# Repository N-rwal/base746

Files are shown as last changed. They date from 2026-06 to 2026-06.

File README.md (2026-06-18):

# base746 Radar Project




---

<details>
<summary>Com fixes</summary>

1. usb fix:  `sudo chmod 666 /dev/ttyACM0`
2. missing arch module: `sudo pacman -S openocd libusb`

</details>

**Description du capteur ou de l'actionneur**

 

Le LD2450 est un module de capteur de suivi de cible en mouvement de la série de radars à ondes millimétriques Hilink 24G.
Il comprend un capteur radar 24 GHz extrêmement simplifié et un micrologiciel doté d'un algorithme intelligent. Cette solution est principalement utilisée dans des environnements intérieurs tels que les maisons, les bureaux et les hôtels pour permettre le suivi de la localisation de personnes en mouvement. Le capteur est composé d'une puce radar à ondes millimétriques AloT, d'une antenne microruban haute performance à un émetteur et deux récepteurs, d'un microcontrôleur économique et de circuits auxiliaires périphériques. Le micrologiciel utilise des formes d'onde FMCW et la technologie de traitement du signal avancée propriétaire de la puce radar.
Il prend en charge la sortie série des données de détection, est prêt à l'emploi et peut être facilement intégré à différents environnements intelligents et produits finaux.

---

**Description de la liaison et principe de fonctionnement hardware
type d'alimentation, type de communication**




Le module LD2450 communique directement via le port série conformément au protocole prescrit pour la sortie des données de résultats de détection:
https://drive.google.com/drive/folders/1kTt0Z3hjKKrIF3OCIDGdwQ4KotDJ8SGA

Les données de sortie série contiennent jusqu'à trois cibles, leur position et leur vitesse, ainsi que d'autres informations. L'utilisateur peut les utiliser de manière flexible
selon les scénarios d'application spécifiques. La tension d'alimentation du module est de 5 V et la capacité de l'alimentation
d'entrée doit être supérieure à 200 mA. Le niveau de sortie E/S du module est de 3,3 V. Le débit en bauds par défaut du port série est de
256 000, avec 1 bit d'arrêt et sans bit de parité. 5.2.

---

**Schéma et typon de raccordement à la carte DISCO**

La carte d'origine est conçue pour accepter les modules de type Arduino Uno.


Nous avons donc utilisé le modèle Arduino. J'ai ajouté au circuit un connecteur XT30 pour l'alimentation par batterie et un port supplémentaire pour les E/S à usage général (GPIO),
au cas où nous en aurions besoin.



Le circuit imprimé obtenu est simple face, plutôt compact et s'adapte comme prévu.


---

**Description de la liaison et principe de fonctionnement software bibliothèques utilisées**

Le fichier LD2450.cpp implémente le pilote radar LD2450 : il lit les octets depuis une interface série matérielle (HardwareSerial), analyse les trames radar pour extraire jusqu’à trois cibles (coordonnées x et y, vitesse, résolution spatiale) et les stocke dans un tampon interne accessible via la fonction getTargets(). Il décode également les valeurs signées 16 bits, reconnaît les trames d’accusé de réception (ACK) et fournit des fonctions d’assistance (setSingleTargetMode, setMultiTargetMode, restart, factoryReset) qui construisent et envoient des trames de commande et attendent (avec un délai d’attente de 200 ms) la réception des accusés de réception correspondants. L’analyse consiste en une simple lecture du tampon qui copie les cibles analysées de manière atomique, et la fonction processByte() ajoute les octets entrants et déclenche l’analyse lorsque suffisamment de données sont accumulées.

---

**Description du fonctionnement de l'application réalisée**

- **Fonction :** Lit les données du radar LD2450 via UART, analyse jusqu'à trois cibles et les affiche sous forme de texte et d'une visualisation graphique simple.
- **Matériel / E/S :** Utilise le port `Serial6` (broches `TX_PIN`/`RX_PIN` → `PC6`/`PC7`) pour communiquer avec le module radar LD2450.
- **Interface utilisateur :** Interface à trois onglets basée sur LVGL : l'onglet 1 affiche les étiquettes `target1_label`, `target2_label` et `target3_label` (texte), l'onglet 2 est `radar_viz_container` avec `target_dots[]` (graphique), l'onglet 3 est un espace réservé.
- **Flux d'exécution :** `mySetup()` construit l'interface utilisateur et configure l'UART, puis lance la tâche FreeRTOS `myTask()`. La fonction `myTask()` lit les octets, appelle `radar.processByte()`, obtient les cibles via `radar.getTargets()`, puis met à jour l'interface utilisateur LVGL (étiquettes + `update_target_dots()`).
- **Logique de visualisation :** `update_target_dots()` convertit les coordonnées en millimètres en positions en pixels, les limite à la zone visible et affiche/masque les points ; des coordonnées nulles signifient « aucune cible ».
- **Remarque concernant la concurrence :** Les mises à jour LVGL sont protégées par `lv_lock()` / `lv_unlock()` car LVGL n'est pas thread-safe.









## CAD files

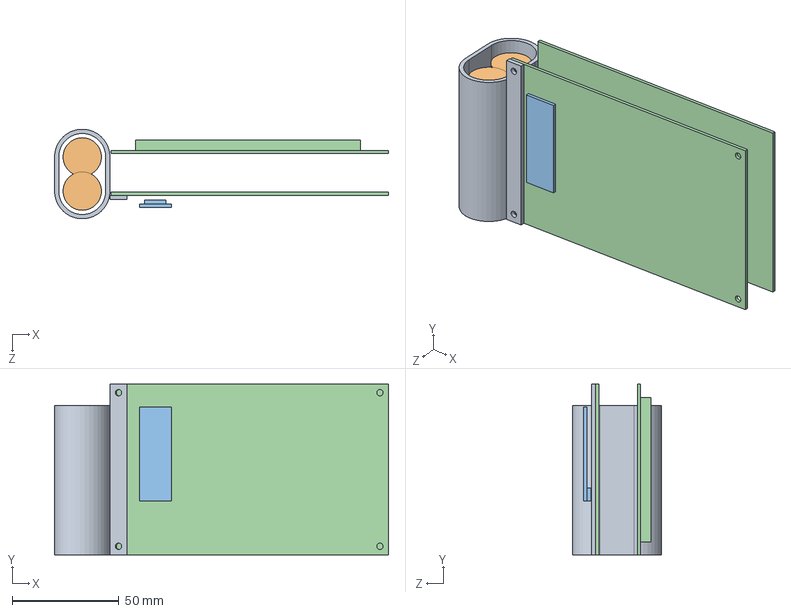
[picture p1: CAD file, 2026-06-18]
project data/radar_handheld/Assemblage1.SLDASM
156.5 x 80.0 x 41.9 mm
stm
radar
cell x 2
holder

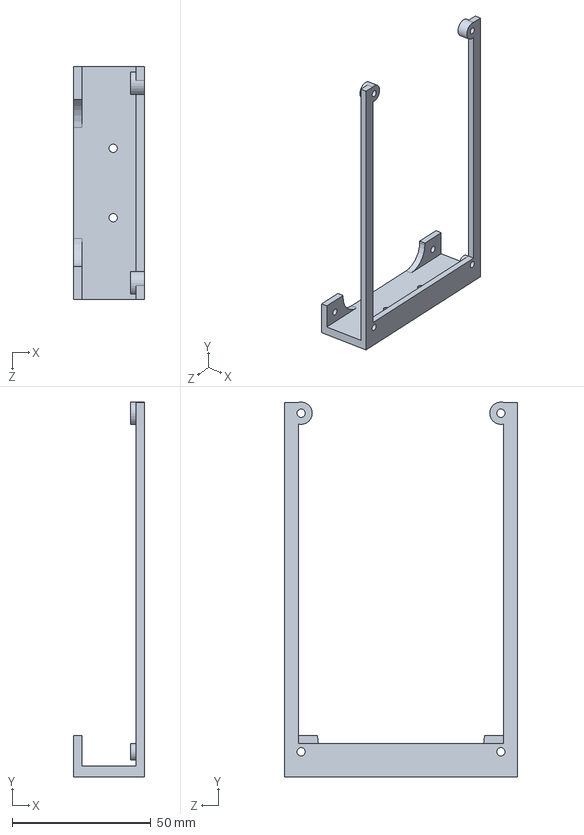
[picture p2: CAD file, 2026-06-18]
project data/radar_handheld/support.SLDPRT
25.5 x 135.1 x 84.0 mm

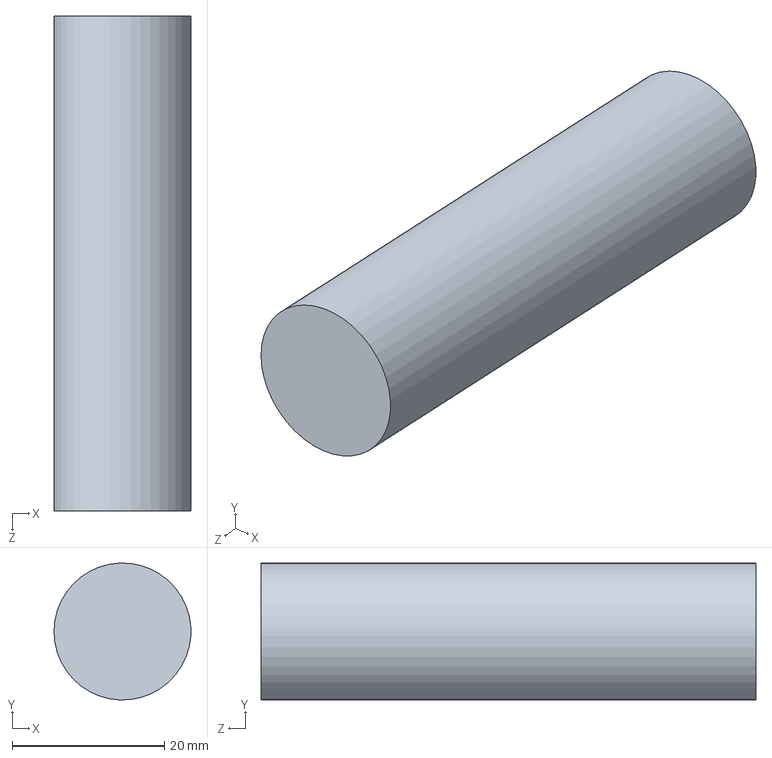
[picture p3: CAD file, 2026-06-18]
project data/radar_handheld/cell.SLDPRT
18.0 x 18.0 x 65.0 mm

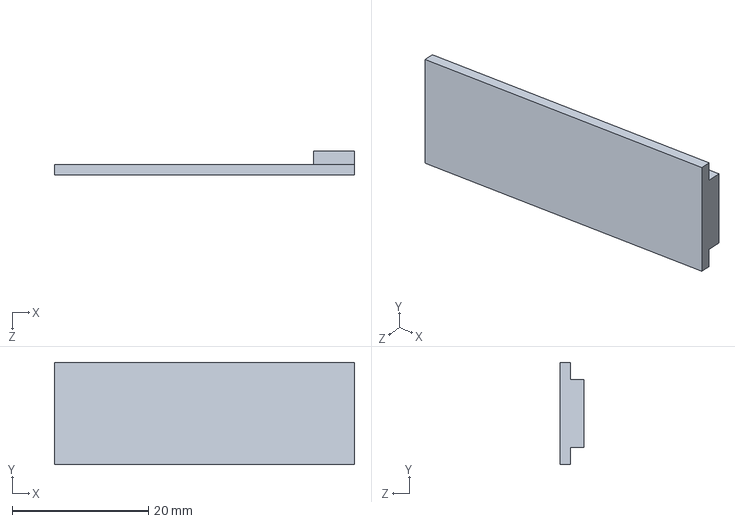
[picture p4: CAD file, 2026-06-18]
project data/radar_handheld/radar.SLDPRT
44.0 x 15.0 x 3.50 mm

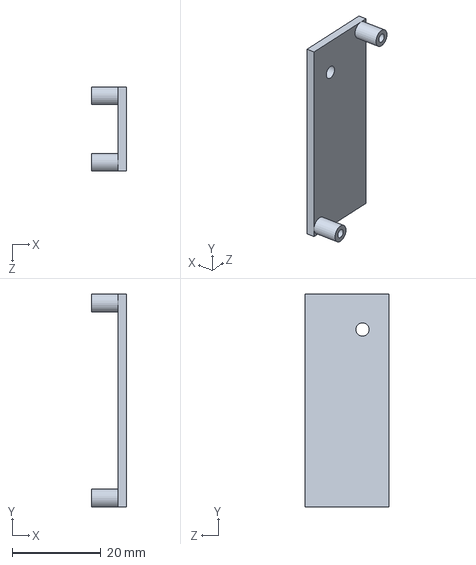
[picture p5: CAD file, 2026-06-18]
project data/radar_handheld/radar_holder.SLDPRT
8.00 x 48.0 x 19.0 mm

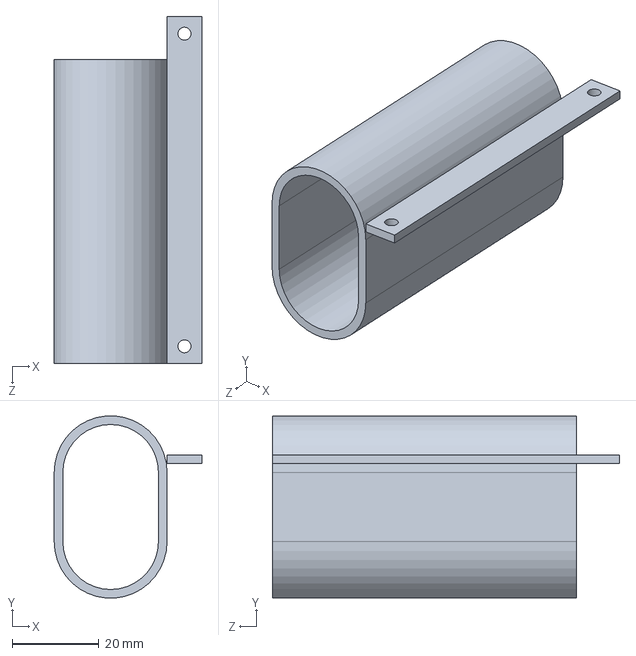
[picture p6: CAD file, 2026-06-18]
project data/radar_handheld/holder.SLDPRT
34.0 x 41.9 x 80.0 mm

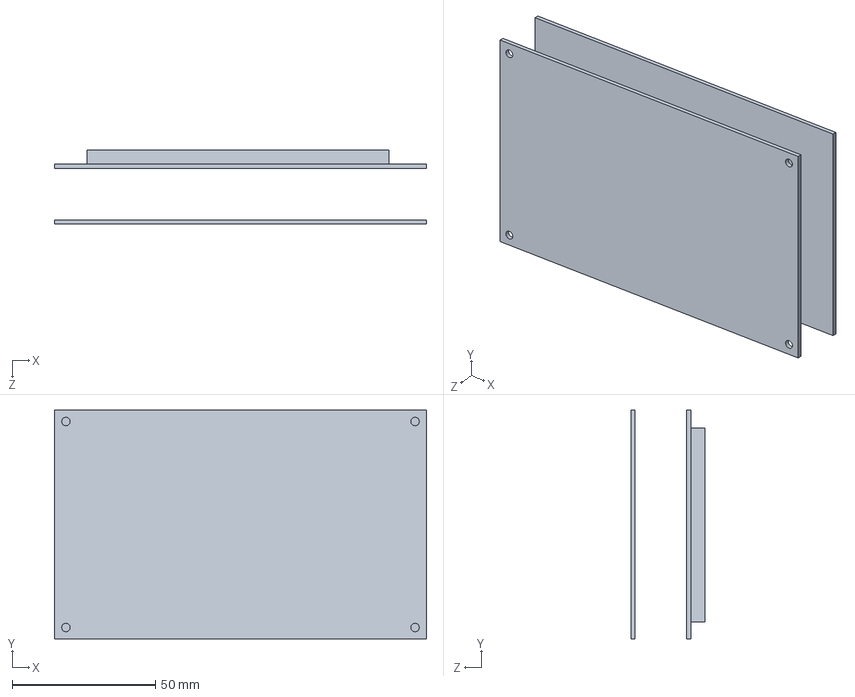
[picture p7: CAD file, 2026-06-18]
project data/radar_handheld/stm.SLDPRT
130.0 x 80.0 x 26.0 mm

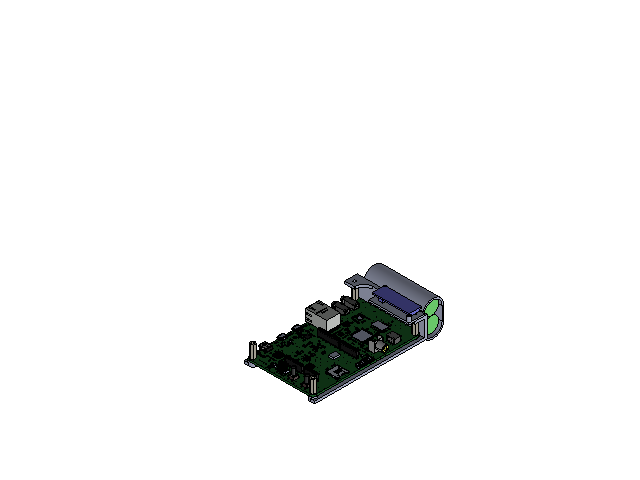
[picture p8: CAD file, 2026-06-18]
project data/radar_handheld/stm32.SLDASM
User_Library-HSMx-A2_A3-xx-xxxxx_SMD_LED_PLCC-4.step
Header_Female_1x10.step
CircuitWorks-SO-8_(PIC12FXXX).step
flipchip.step
bga1x1.step x 2
sj-3523-smt.step x 2
User_Library-SOD323.step x 5
0603R.step x 43
bga4x4.5.step
strbrick.step x 4
CircuitWorks-SOT-223.step x 2
Header_Female_1x6.step
black_6x6.step x 2
0402C.step x 83
User_Library-Tantalum_Capacitor_Case_A_Tantalum_case_A_part1.step x 9
User_Library-Tantalum_Capacitor_Case_A_Tantalum_case_A_part2.step x 18
bga13x13.step
0402R.step x 133
User_Library-dfn6_3x3_rm0_95.step
1206.step x 5
User_Library-QFN-8.step
0805.step x 4
bga8x13.step
xf2m-3015-1a.step
lcd.step
CircuitWorks-SOT-23-5.step x 3
RJ45.step
User_Library-QFN24_4x4_Imported.step
User_Library-QFN24_4x4_Imported_2.step
User_Library-QFN24_4x4_Imported_3.step
User_Library-QFN24_4x4_Imported_4.step
User_Library-QFN24_4x4_Imported_5.step
User_Library-QFN24_4x4_Imported_6.step
User_Library-QFN24_4x4_Imported_7.step
User_Library-QFN24_4x4_Imported_8.step
User_Library-QFN24_4x4_Imported_9.step
User_Library-QFN24_4x4_Imported_10.step
User_Library-QFN24_4x4_Imported_11.step
User_Library-QFN24_4x4_Imported_12.step
User_Library-QFN24_4x4_Imported_13.step
User_Library-QFN24_4x4_Imported_14.step
User_Library-QFN24_4x4_Imported_15.step
User_Library-QFN24_4x4_Imported_16.step
User_Library-QFN24_4x4_Imported_17.step
User_Library-QFN24_4x4_Imported_18.step
User_Library-QFN24_4x4_Imported_19.step
User_Library-QFN24_4x4_Imported_20.step
User_Library-QFN24_4x4_Imported_21.step
User_Library-QFN24_4x4_Imported_22.step
User_Library-QFN24_4x4_Imported_23.step
User_Library-QFN24_4x4_Imported_24.step
User_Library-QFN24_4x4_Imported_25.step
User_Library-QFN24_4x4_Imported_26.step
User_Library-QFN24_4x4_Imported_27.step
User_Library-QFN24_4x4_Imported_28.step
1241050-4[1].step
User_Library-sot353.step x 2
SSM-104-L-DH_body.step
C-58-08,_C-58-074.step
usb_a-usb_b-m5-smd-c.step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

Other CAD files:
project data/radar_handheld/holder.STL
project data/radar_handheld/radar_holder.STL
project data/radar_handheld/support.3mf
project data/radar_handheld/support.STL

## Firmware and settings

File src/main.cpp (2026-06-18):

#include "lvgl.h"            // LittlevGL (LVGL) graphics library
#include "lvglDrivers.h"    // Platform-specific LVGL drivers (display, input)
#include <Arduino.h>         // Arduino compatibility layer / FreeRTOS helpers
#include "LD2450.h"         // LD2450 radar driver (parses radar frames)

#define TX_PIN PC6  // UART TX pin connected to radar module
#define RX_PIN PC7  // UART RX pin connected to radar module

// LVGL object handles used throughout the UI
static lv_obj_t *radar_viz_container; // container for radar visualization (Tab 2)
static lv_obj_t *uart_display_label; // reserved for UART debug display (unused)

// Serial interface wired to the LD2450 radar module
HardwareSerial Serial6(USART6); 

// Labels that show numeric/readable target info on Tab 1
static lv_obj_t *target1_label;
static lv_obj_t *target2_label;
static lv_obj_t *target3_label;

// Small dot objects used to render targets on the visualization (Tab 2)
static lv_obj_t *target_dots[3];

// Radar parser/manager instance. The LD2450 class reads bytes
// from the UART and exposes parsed target data.
LD2450 radar(&Serial6);

// Pre-allocated array for up to 3 detected targets.
LD2450_Target targets[3];

// Forward declarations for RTOS tasks and LVGL event handler
void myTask(void *pvParameters);
static void event_handler(lv_event_t * e);
void uiTask();

// Map radar coordinates (millimeters) into pixel positions inside
// the visualization container and show/hide the dot objects.
// - targets: array of detected targets (x forward, y lateral, etc.)
// - container: LVGL object that defines the visual area (unused, kept for API clarity)
void update_target_dots(LD2450_Target targets[3], lv_obj_t *container) {
  for (int i = 0; i < 3; i++) {
    // If target coordinate is non-zero, consider it a valid detection
    if (targets[i].x != 0 || targets[i].y != 0) {
      // Convert mm coordinates to pixel positions (ad-hoc scaling)
      int px = 200 + (targets[i].x * 200 / 2500);
      int py = 230 - (targets[i].y * 220 / 7000);

      // Clamp to the visualization bounds so dots remain visible
      if (px < 5) px = 5;
      if (px > 395) px = 395;
      if (py < 5) py = 5;
      if (py > 245) py = 245;

      // Position the dot (subtract half size to center)
      lv_obj_set_pos(target_dots[i], px - 5, py - 5);
      lv_obj_clear_flag(target_dots[i], LV_OBJ_FLAG_HIDDEN);
    } else {
      // No valid target: hide the dot
      lv_obj_add_flag(target_dots[i], LV_OBJ_FLAG_HIDDEN);
    }
  }
}

// Equivalent of Arduino's setup(): initialize UI, UART and start task
void mySetup()
{
  // Build the LVGL UI elements
  uiTask();

  // Configure the hardware UART pins used by the radar
  Serial6.setTx(TX_PIN);
  Serial6.setRx(RX_PIN);
  Serial6.begin(115200);
  Serial6.setTimeout(10);

  // Create a FreeRTOS task that will read/process radar data
  xTaskCreate(myTask, "RadarTask", 2048, NULL, 2, NULL);
}

// Main loop is intentionally empty: the real work happens in RTOS tasks.
void loop()
{
  // Yield for a while to avoid busy-waiting.
  vTaskDelay(pdMS_TO_TICKS(1000));
}

// RTOS task: reads UART bytes, feeds parser and updates LVGL UI
void myTask(void *pvParameters)
{
  // Small initial delay to allow system startup
  vTaskDelay(pdMS_TO_TICKS(100));

  while (1)
  {
    // Drain incoming bytes from the radar UART and feed parser
    while (Serial6.available())
    {
      uint8_t c = Serial6.read();
      radar.processByte(c);
    }

    // Retrieve parsed target list from the radar object
    radar.getTargets(targets);
    
    // LVGL is not thread-safe: lock before modifying UI state
    lv_lock();
    
    char display_str[80];
    
    // Format and update Target 1 label (or show placeholder)
    if (targets[0].x != 0 || targets[0].y != 0) {
      snprintf(display_str, sizeof(display_str),
               "Target 1: x=%5d mm, y=%5d mm, sp=%3d cm/s",
               targets[0].x, targets[0].y, targets[0].speed);
    } else {
      snprintf(display_str, sizeof(display_str), "Target 1: ---");
    }
    lv_label_set_text(target1_label, display_str);
    
    // Format and update Target 2 label
    if (targets[1].x != 0 || targets[1].y != 0) {
      snprintf(display_str, sizeof(display_str),
               "Target 2: x=%5d mm, y=%5d mm, sp=%3d cm/s",
               targets[1].x, targets[1].y, targets[1].speed);
    } else {
      snprintf(display_str, sizeof(display_str), "Target 2: ---");
    }
    lv_label_set_text(target2_label, display_str);
    
    // Format and update Target 3 label
    if (targets[2].x != 0 || targets[2].y != 0) {
      snprintf(display_str, sizeof(display_str),
               "Target 3: x=%5d mm, y=%5d mm, sp=%3d cm/s",
               targets[2].x, targets[2].y, targets[2].speed);
    } else {
      snprintf(display_str, sizeof(display_str), "Target 3: ---");
    }
    lv_label_set_text(target3_label, display_str);
    
    // Update visual dot positions on Tab 2
    update_target_dots(targets, radar_viz_container);
    
    // Release LVGL lock
    lv_unlock();

    // Short delay to yield CPU and control update rate
    vTaskDelay(pdMS_TO_TICKS(10));
  }
}

// Simple LVGL event handler used as an example hook for interactive widgets
static void event_handler(lv_event_t * e)
{
  lv_event_code_t code = lv_event_get_code(e);
  if (code == LV_EVENT_CLICKED)
    LV_LOG_USER("Clicked");
  else if (code == LV_EVENT_VALUE_CHANGED)
    LV_LOG_USER("Toggled");
}

// Build the user interface (LVGL): a 3-tab view with
// - Tab 1: textual target readouts
// - Tab 2: radar visualization with dots and reference lines
// - Tab 3: placeholder
void uiTask()
{
  /*Create a Tab view object*/
  lv_obj_t * tabview;
  tabview = lv_tabview_create(lv_screen_active());
  lv_tabview_set_tab_bar_position(tabview, LV_DIR_RIGHT);
  lv_tabview_set_tab_bar_size(tabview, 80);

  lv_obj_set_style_bg_color(tabview, lv_palette_lighten(LV_PALETTE_GREEN, 2), 0);

  lv_obj_t * tab_buttons = lv_tabview_get_tab_bar(tabview);
  lv_obj_set_style_bg_color(tab_buttons, lv_palette_darken(LV_PALETTE_GREY, 3), 0);
  lv_obj_set_style_text_color(tab_buttons, lv_palette_lighten(LV_PALETTE_GREY, 5), 0);
  lv_obj_set_style_border_side(tab_buttons, LV_BORDER_SIDE_RIGHT, LV_PART_ITEMS | LV_STATE_CHECKED);

  lv_obj_t * tab1 = lv_tabview_add_tab(tabview, "Mode 1");
  lv_obj_t * tab2 = lv_tabview_add_tab(tabview, "Mode 2");
  lv_obj_t * tab3 = lv_tabview_add_tab(tabview, "Mode 3");

  /* Tab 1 content - Radar readings */
  lv_obj_t * radar_container = lv_obj_create(tab1);
  lv_obj_set_width(radar_container, lv_pct(100));
  lv_obj_set_height(radar_container, LV_SIZE_CONTENT);
  lv_obj_align(radar_container, LV_ALIGN_TOP_LEFT, 10, 10);
  lv_obj_set_style_border_width(radar_container, 1, 0);
  lv_obj_set_style_pad_all(radar_container, 10, 0);
  
  // Target 1 label (red theme)
  target1_label = lv_label_create(radar_container);
  lv_label_set_text(target1_label, "Target 1: ---");
  lv_obj_set_style_text_color(target1_label, lv_palette_main(LV_PALETTE_RED), 0);
  lv_obj_align(target1_label, LV_ALIGN_TOP_LEFT, 0, 0);
  
  // Target 2 label (green theme)
  target2_label = lv_label_create(radar_container);
  lv_label_set_text(target2_label, "Target 2: ---");
  lv_obj_set_style_text_color(target2_label, lv_palette_main(LV_PALETTE_GREEN), 0);
  lv_obj_align(target2_label, LV_ALIGN_TOP_LEFT, 0, 30);
  
  // Target 3 label (blue theme)
  target3_label = lv_label_create(radar_container);
  lv_label_set_text(target3_label, "Target 3: ---");
  lv_obj_set_style_text_color(target3_label, lv_palette_main(LV_PALETTE_BLUE), 0);
  lv_obj_align(target3_label, LV_ALIGN_TOP_LEFT, 0, 60);

  /* Tab 2 content - radar visualization */
  radar_viz_container = lv_obj_create(tab2);
  lv_obj_set_size(radar_viz_container, 400, 250);
  lv_obj_center(radar_viz_container);
  lv_obj_set_style_bg_color(radar_viz_container, lv_color_hex(0x1a1a2e), 0);
  lv_obj_set_style_border_width(radar_viz_container, 2, 0);
  lv_obj_set_style_border_color(radar_viz_container, lv_palette_main(LV_PALETTE_GREY), 0);
  
  lv_obj_remove_flag(radar_viz_container, LV_OBJ_FLAG_SCROLLABLE);
  lv_obj_set_scrollbar_mode(radar_viz_container, LV_SCROLLBAR_MODE_OFF);
  
  // Add static reference lines for visual reference
  // Center line (X=0)
  lv_obj_t * center_line = lv_obj_create(radar_viz_container);
  lv_obj_set_size(center_line, 1, 220);
  lv_obj_set_pos(center_line, 200, 15);
  lv_obj_set_style_bg_color(center_line, lv_color_hex(0x444466), 0);
  lv_obj_set_style_border_width(center_line, 0, 0);
  lv_obj_remove_flag(center_line, LV_OBJ_FLAG_SCROLLABLE);
  
  // Horizontal reference line at mid-distance (Y=3500mm)
  lv_obj_t * mid_line = lv_obj_create(radar_viz_container);
  lv_obj_set_size(mid_line, 380, 1);
  lv_obj_set_pos(mid_line, 10, 115);
  lv_obj_set_style_bg_color(mid_line, lv_color_hex(0x444466), 0);
  lv_obj_set_style_border_width(mid_line, 0, 0);
  lv_obj_remove_flag(mid_line, LV_OBJ_FLAG_SCROLLABLE);
  
  // Bottom line (radar position)
  lv_obj_t * radar_line = lv_obj_create(radar_viz_container);
  lv_obj_set_size(radar_line, 380, 1);
  lv_obj_set_pos(radar_line, 10, 230);
  lv_obj_set_style_bg_color(radar_line, lv_color_hex(0xff6666), 0);
  lv_obj_set_style_border_width(radar_line, 0, 0);
  lv_obj_remove_flag(radar_line, LV_OBJ_FLAG_SCROLLABLE);
  
  // Add labels for distances
  lv_obj_t * dist_7m = lv_label_create(radar_viz_container);
  lv_label_set_text(dist_7m, "7m");
  lv_obj_set_style_text_color(dist_7m, lv_color_hex(0x888888), 0);
  lv_obj_set_style_text_font(dist_7m, &lv_font_montserrat_14, 0);
  lv_obj_set_pos(dist_7m, 360, 10);
  lv_obj_remove_flag(dist_7m, LV_OBJ_FLAG_SCROLLABLE);
  
  lv_obj_t * dist_35m = lv_label_create(radar_viz_container);
  lv_label_set_text(dist_35m, "3.5m");
  lv_obj_set_style_text_color(dist_35m, lv_color_hex(0x888888), 0);
  lv_obj_set_style_text_font(dist_35m, &lv_font_montserrat_14, 0);
  lv_obj_set_pos(dist_35m, 360, 105);
  lv_obj_remove_flag(dist_35m, LV_OBJ_FLAG_SCROLLABLE);
  
  // Create 3 dots for targets (initially hidden)
  target_dots[0] = lv_obj_create(radar_viz_container);
  target_dots[1] = lv_obj_create(radar_viz_container);
  target_dots[2] = lv_obj_create(radar_viz_container);
  
  for (int i = 0; i < 3; i++) {
    lv_obj_set_size(target_dots[i], 10, 10);
    lv_obj_set_style_radius(target_dots[i], LV_RADIUS_CIRCLE, 0);
    lv_obj_set_style_bg_opa(target_dots[i], LV_OPA_COVER, 0);
    lv_obj_set_style_border_width(target_dots[i], 1, 0);
    lv_obj_set_style_border_color(target_dots[i], lv_color_hex(0xffffff), 0);
    lv_obj_add_flag(target_dots[i], LV_OBJ_FLAG_HIDDEN);
    lv_obj_remove_flag(target_dots[i], LV_OBJ_FLAG_SCROLLABLE);
  }
  
  // Set colors
  lv_obj_set_style_bg_color(target_dots[0], lv_palette_main(LV_PALETTE_RED), 0);
  lv_obj_set_style_bg_color(target_dots[1], lv_palette_main(LV_PALETTE_GREEN), 0);
  lv_obj_set_style_bg_color(target_dots[2], lv_palette_main(LV_PALETTE_BLUE), 0);

  /* Tab 3 content - Empty for now */
  lv_obj_t * label_tab3 = lv_label_create(tab3);
  lv_label_set_text(label_tab3, "Mode 3 - Coming Soon");
  lv_obj_center(label_tab3);

  lv_obj_remove_flag(lv_tabview_get_content(tabview), LV_OBJ_FLAG_SCROLLABLE);
}
